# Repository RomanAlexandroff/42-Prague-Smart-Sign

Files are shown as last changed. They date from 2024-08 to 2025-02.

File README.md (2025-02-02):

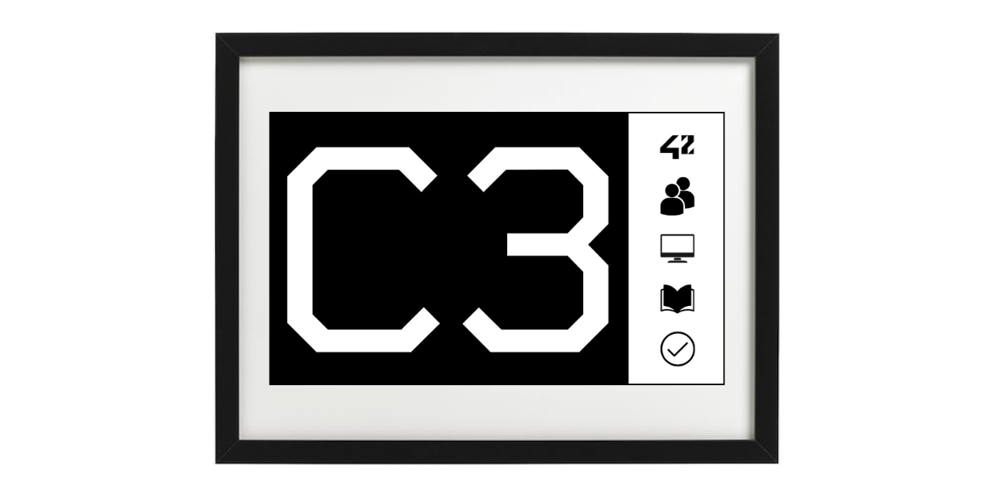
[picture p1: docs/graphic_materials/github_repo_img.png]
Repository Banner

# 42 Smart Cluster Sign
## Table of Contents

- [Introduction](#introduction)
- [Usage](#usage)
- [Features](#features)
- [Components](#components)
- [Contributing](#contributing)
- [Suggestions for Contributions](#suggestions-for-contributions)
- [Regards](#regards)
- [License](#license)
- [Conclusion](#conclusion)

## Introduction

Welcome to the README for the 42 Smart Cluster Sign — a self-sufficient information display designed to be installed on a cluster door. Its purpose is to notify students when the cluster is reserved for an exam and prevent them from accidental entering. The device automatically retrieves exam dates from Intra and displays appropriate warnings and information on its e-paper screen. In the spare time it simply displays the cluster number.

For more information, please, refer to the technical documentation in the docs folder of this repository.

## Usage

Once the 42 Smart Cluster Sign is installed and powered on, it will automatically retrieve exam dates from Intra and update the display accordingly. The device operates in the following states:
1. **Normal state**: The device displays the number of the cluster, accompanied by pictograms that depict some of the cluster use cases: cooperating with fellow peers, working on a computer, and studying from books. The last pictogram indicates "free to enter" contrasting with the "do not enter" cross pictogram that appears during exams. In case the Sign needs to communicate an issue with its operation, the pictograms are replaced with an appropriate error message, e.g.: "Low battery" or "Could not get exam info".
2. **Pre-exam warning**: On the day of an exam, the device hides the pictograms and adds a small warning note informing students of an upcoming exam later in the day. This way, students who want to settle into the room can plan their work with the cluster availability limitations in mind.
3. **1-hour countdown**: 1 hour before the exam, a countdown begins. The device no longer displays the cluster number but a full-screen sign with the minutes left until the exam, indicating to students that it is time to vacate the classroom.
4. **Exam in progress**: During the exam, the device displays a big bright-red warning sign indicating the ongoing exam. The drastically changed colour palette attracts attention, enhancing the sign's effectiveness.
5. **Post-exam state**: After the exam ends, the Sign returns to its normal state, displaying the number of the cluster.

## Features

- Highly autonomous operation: the Sign operates fully autonomously and does not require any input from the school personnel;
- Automatic exam time check: the Sign keeps track of the exams published on Intra on its own;
- Adaptation to changes: the Sign can adapt its behaviour to some unusual exam scheduling, such as last-minute cancellations, varying exam lengths, or sequences of several immediate exams;
- Exam subscribers check: if there is noone undertaking the exam, the Sigh will know it and will not block the room;
- Automatic battery charge monitoring: you will surely know when to charge the device;
- Deep Sleep mode: the microcontroller sleeps most of the time and wakes up only when it has a task to do, drastically saving the battery charge;
- Telegram enabled: control the Sign, update its security token, and receive operational information — all remotely, via your Telegram chat;
- Over The Air firmware update: develop and upload new features without the need of looking for a cable;
- Watchdog: no program failure can stop the Sign as its inner watchdog makes sure the program execution does not get stuck;
- Low-maintenance design: the 4000mAh battery ensures long periods of operation - up to a few months - between recharges, which require a standard USB-C cable and any 5V power adapter. During recharging, the Sign remains fully operational.

## Components

The following components are used in the 42 Smart Cluster Sign:
1. **Seeed Studio XIAO ESP32C3 Wi-Fi module**: provides connectivity to the Internet for retrieving exam dates, updates the display, takes care of the battery with its battery management and charging circuit — all of that while rocking modern USB-C port for charging and easy software updating.
2. **Good Display GDEY075Z08 7.5" 800x480 ePaper black/red/white SPI display**: a high-resolution display that allows for clear and easy-to-read information.
3. **Good Display DESPI-C02 universal SPI e-Paper adapter**: transforms display's FPC interface into microcontroller's SPI.
4. **4000mAh Li-ion battery with overcharge and undercharge protection**: powers the device and ensures continuous operation.
5. **IKEA RÖDALM photo frame, black, 13x18 cm**: made a good enclosure.
6. **Custom 3D-printed board**: to hold all the electronics in place.

For more information, please, refer to the bill of materials in the docs folder of this repository.

## Contributing

Contributions to the 42 Smart Cluster Sign project are welcome! If you have any ideas, bug fixes, or improvements, feel free to open an issue, fork or submit a pull request on the GitHub repository.

When contributing, please adhere to the existing code style and follow the established guidelines. Clearly describe your changes and provide any necessary documentation or tests.

## Suggestions for Contributions

**good first contributions**
- Core temperature monitoring as a safety mechanism: the temperature being too high may signal some serious hardware failure and a safety threat, e.g. the battery has the lowest maximum allowed operational temperature of 60°C — notify the Telegram chat if the temperature of the core gets at least to 50°C;
- Forced display refresh: the Sign is programed not to refresh the content on the display unless it is absolutely necessary, but this approach causes some graphical artifacts to appear with time. Add a scheduled full display cleaning. Once a week is enough. Preferably in the night when noone can see it. After the cleaning process is done, the Sign may not stay blank and shall display relevant information.
- Refactor the project to lower the number of the Common global (com_g) variables. But DO NOT alter the RTC global (rtc_g) variables unless you are absolutely certain of what you are doing;
- Add a countdown till the end of an ongoing exam like the already existing one till the start of an upcoming exam. 

**advanced contributions**
- Adding a "DO NOT ENTER!" sign that can be displayed or errased from the screen by pressing the WARNING_BUTTON button;
- Core temperature monitoring as a mechanism for detecting the battery charging process being finished: when the battery is being charged, the core temperature of the microcontroller rises approximatelly 10°C above its common operational temperature and then drops back down when finished charging — notify the Telegram chat when charging is finished. This functionality may not block the Sign from fulfilling its main goal of notifying students about exams;
- Logging error messages into a log file in the microcontroller's memory and the log file extraction mechanism;
- The direct OTA implementation - the Sign itself creates a Wi-Fi access point that you can connect to and to update the firmware without the need of a Wi-Fi modem in the middle;
- Replacing Telegram with Slack: refactoring all the Sign's Telegram functionality to work via Slack would allow integrating the Sign better into the 42 ecosystem as well as developing new functionality, e.g. notifying all the students about an upcomming exam.

The **Issues** tab of this repository may also be worth checking, as it might contain suggestions that have not yet made their way onto this list.

## Regards

This project is a group effort of various 42 students with support from the 42 Prague Bocal team. Here they are:
- **raleksan**, 42 Prague — software and electronic hardware developer. Made the idea reality,
- **gsura**, 42 Prague — idea starter and motivation supporter. Pitched the idea to Bocal so well they ended up asking for two devices,
- **cgray**, 42 Prague — hardware development. Modeled beautiful and functional inner frame for the electronics,
- **phelebra**, 42 Prague — 3D printing. Turned 3D model into high-quality pieces of hardware.
- **arosado-**, 42 Lisboa — 42 API expert. Tought how to get the data from the 42 servers,
- **jrathelo**, 42 Nice — memory wizard. Helped resolve the microcontroller's RAM overflow.

The project is based on Jean-Marc Zingg's [GxEPD2](https://github.com/ZinggJM/GxEPD2) library for e-paper displays.
The project uses the [ArduinoOTA](https://github.com/jandrassy/ArduinoOTA) library by Juraj Andrassy for the Over-The-Air software update functionality.
The Sign's Telegram Bot functionality is provided by Brian Lough's [UniversalTelegramBot](https://github.com/witnessmenow/Universal-Arduino-Telegram-Bot) library.

## License

The 42 Smart Cluster Sign project is licensed. Please, familiarise yourself with the license before using the software or working on it. The text of the license can be found in this repository.

Please note that while the project strives to provide accurate information, it is provided "as is" without any warranty. Use the project at your own risk.

## Conclusion

Thank you for your interest in the 42 Smart Cluster Sign project! We hope this README provides you with the necessary information to understand the project's purpose, features, installation process, usage, and maintenance. If you did not find the information you need, please, refer to the technical documentation in this repository. If you have any further questions or need assistance, please don't hesitate to reach out. Happy coding!

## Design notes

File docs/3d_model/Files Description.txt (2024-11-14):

The Sign Frame model

This folder contains .STL files for the Sign's
inner frame. The frame is divided into two files
to ease printing. The two printed parts must be
glued together.

The sockets fit only the parts stated in the Bill
of Materials file.

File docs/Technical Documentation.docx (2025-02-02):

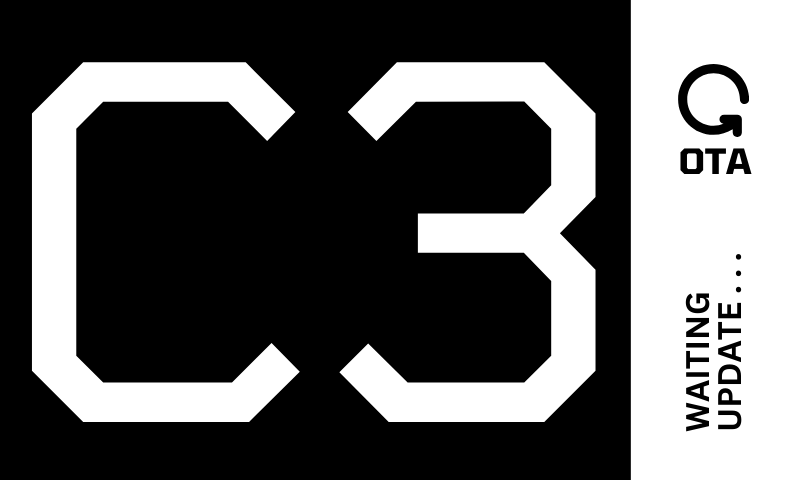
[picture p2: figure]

[This document contains detailed information about the project and was created as a go-to place to find answers to all of your HOWs and WHYs, so the software support and further project development are easier.]

[ January 2025 ]

[42 smart cluster sigN.]

[technical documentation.]

[Table of contents.]

[SUMMARY.]

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
About the project //TO-DO

Contractor's requirements

General description of the program run

Program run step-by-step //TO-DO

Getting ready to maintain and develop the project

Hardware maintenance

Program files description

The config file

Functions description

How to get exams info from Intra

Graphics //TO-DO

How to draw on the display //TO-DO

Service messages meaning //TO-DO

Libraries and their use

Bugs and suggestions how to fix them

New bugs and Future development suggestions

Suggestions for dealing with confidential information

Sources

//TO-DO:

Hardware description

Circuit diagrams and schematics

Description of the program constants

Architectural decisions explained

Power management

Safety considerations

The Don’ts of changing the program

Used terms

[ABOUT THE PROJECT.]

This project is designed to manage and display information on a smart sign for a 42 campus cluster. The sign displays various messages and images, including exam schedules, battery status, and OTA updates. It communicates with the 42 Intra API and a Telegram bot to fetch and display relevant information.

[Contractor's Requirements.]

[and how the sign matches them.]

The finished device must fulfill the following requirements:

1. Auditorium status display: the device must always display the current status of the auditorium, indicating whether it is free or if an exam is in progress.  — The Sign displays the number of the auditorium in calm black and white colours to indicate that the room is available for everyone or it displays the „exam in progress“ sign in bright red and black colours to show that the room shall not be entered by those who do not participate in the exam. The Sign is never blank.
2. Advance notification: the device should notify students in advance on exam days about the need to vacate the auditorium.  — The Sign displays a note with the exact time of the upcoming exam right from the morning of that day. 1 hour before the exam the black-white-and-red „reserve for exam“ sign with time left starts being displayed.
3. Autonomy: the device must operate independently, performing its tasks and solving problems that arise without requiring the time or intervention of the educational institution's staff.  — The Sign can connect to the Internet, access the institution server API and pull exams date and time. This is how it knows when to display the apropriate state of the auditorium. The Sign software is designed with all the common negative situations in mind which ensures the Sign does not bother anyone unless it absolutely needs to.
4. Problem reporting: the device must be capable of reporting issues that cannot be resolved without assistance from the educational institution's staff.  — When the Sign fails to resolve an unordinary situation itself and requires assistance, it displays an apropriate error message on its display as well as sends a detailed error report to its Telegram chat.
5. Support and expandability: the device should be designed for support and expansion, allowing any student of the educational institution to contribute to the project, develop new functionality, and upload new software onto the device.  — The Sign project was chosen to be made using Arduino IDE as the most beginners-friendly developing platform. The software was developed using a straightforward bare-metal approach to maintain easy-to-follow program logic. The Sign has a standart USB-C port for flashing its software, monitoring its Serial port and charging its battery. The microcontroller used in the project has inner USB controller which eliminates the need of using a UART-TTL adapter. The microcontroller pins are equipped with standart Dupont sockets which allows anyone to change used pins and add new hardware by simply connecting it to the microcontroller with Dupont cables. The Sign is securelly fixed on the wall with 4 furniture double ball catches, which at the same time allow to take the Sign off the wall for maintanance.
6. Safety: the device must ensure safety by incorporating protective elements for potentially dangerous electronic components.  — The battery used in the project has an embedded protection against shortcuts, overcharging and ungercharging, which has the ability of completely disconnecting the battery from the rest of the circuit. The battery charging IC is capable of adapting its charging power, applying lower voltages when the battery is low on charge or close to being fully charged. The charging IC generally uses slightly lower charging rate than the standart charging rate for this particular battery, which will result in the battery longer life.
7. Rechargeable operation: the device must operate on a rechargeable battery, include a common charging connector, and provide indications for the charging process and its completion.  — The Sign employs an internal high-capacity rechargeable battery, which insures a long lasting operation without the need of changing batteries. The battery can be recharged by plugging the Sign into any 5V power adapter. The Sign has a USB-C connector for recharging the battery as well as for flashing the software. The Sign employs a red LED to indicate an ongoing charging process.
8. Design compatibility: both the graphical user interface (GUI) and the physical appearance of the device must align with the established style of the educational institution's interior design.  — The body of the Sign is made of black wooden frame with mate finish, which perfectly matches the mate-black profile of the auditorium glass door. The GUI was designed inspired by the painings on the walls of the institution as well as the „42“ logo, thus nicely matching the overal style of the interiors.

[General description of the program run.]

Let's take a look at one day of the 42 Smart Cluster Sign‘s life. Let’s say that on this particular day there is an exam scheduled for 13:00 and it will last for 3 hours.

It is still night and the Sign is showing the cluster number with the default icons from the day before, while still being asleep. It is normal for the Sign to sleep all the time. It has its scheduled hours to wake up and check if something needs to be done. They are 6, 9, 12, 15, 18 and 21 o’clock (could have been changed in the program). But it is still too early.

Time passes by. Now, it is 6:00 in the morning. The Sign wakes up to check if there are exams today. It goes online, pulls the information from the Intra server and sees that there will be an exam starting at 13:00 and ending at 16:00. The Sign replaces the default icons from yesterday with a note “The cluster will be reserved for an exam today at 13:00” while still displaying the cluster number. Since there is nothing more for the Sign to do, it sets its alarm clock for 12:00 - an hour before the exam - and goes back to sleep.

It is 12 o'clock and the Sign wakes up again to get ready for the exam. It checks Intra to make sure the exam was not canceled during its sleep and that there is at least 1 person attending. If everything checks, it replaces the cluster number with a big warning sign that says: “RESERVATION! The cluster is reserved for an exam. Please, vacate it in due time. You have XX minutes left”. Instead of XX it first says 50 minutes, then 25 minutes and finally 5 minutes left.

Finally, it is 13:00. The exam begins. The Sign changes the previous warning sign for a new one, saying “DO NOT ENTER! Exam in progress!”. At this point the Sign has nothing else to do, so again it sets its alarm clock for 16:00 - the end of the exam - and goes to sleep.

At 16 o'clock the Sign wakes up, checks Intra, finds no more exams for today, replaces the warning sign with a cluster number with the default icons, sets its alarm clock until the next scheduled wake up - in this case 18:00 - and goes back to sleep.

At 18 o'clock the Sign wakes up, checks Intra and finds no more exams. Later, at 21 o’clock it wakes up for the last time today, finding nothing more to be done. Its work for today is over. It goes to sleep to wake up again the next morning at 6.

[PROGRAM RUN STEP-BY-STEP.]

STARTING THE PROGRAM

1. Turning on

2. Initializing the Serial Port

• Outputting a dash to the serial port gives time to synchronize data transfer with the computer and avoid losing important data

3. Initializing the file system

• If the file system initialization fails, the following functions will not be available: restoring the last used Telegram chat, the Secret value, and the OTA flag value after reinstalling the program, after a power outage, or after a software reset (i.e. after all cases when RTC memory data is lost); record the value of the last used Telegram chat, the Secret value and the OTA flag value

4. initialize the buttons (disabled due to bugs)

5. initialize ADC for battery measurements

6. initialize the SPI port of the display

7. check the reboot reason

• also restores the value of the last used Telegram chat, the Secret value and the OTA flag value after reinstalling the program, after a power outage or after a software reset (i.e. after all cases when RTC memory data is lost)

• also puts the device to sleep for 24 hours if the BROWN OUT detector is triggered. It is triggered if the battery charge is insufficient to continue operation. In this case, [DEVICE OPERATION ENDS HERE] until the battery is charged.

8. battery check

• due to the technical features of the device, we can determine the battery charge level only when it is almost discharged. Accurate battery measurements can be taken approximately between 3% and 0% of the battery charge. In ADC readings, this corresponds to 800 and 400.

• take 5 measurements of the charge level and calculate their average value

• all readings above 800 mean that the battery is sufficiently charged and there is no need to report a low battery - exit the function

• connect to Wi-Fi to report the battery status to Telegram

• all readings below 400 mean a completely discharged battery. Despite the fact that the BROWN OUT detector did not work in the previous step, you cannot continue working with such a low charge. We report a low battery in Telegram, display the message "Low battery" on the display and put the device to sleep for 24 hours. In this case, [DEVICE OPERATION ENDS HERE] until the battery is charged.

• indicators between 700 and 600 may mean that the device is charging

• if we still haven't exited the function, but the indicators are below 800, then the battery is already discharged, but we can still continue working. We report the discharged battery in Telegram, display the message "Low battery" on the display and continue executing the program.

9. initializing the OTA function (disabled due to blocking by the firewall)

10. switching to OTA mode (disabled due to blocking by the firewall)

11. choosing which mode to continue working in: in cluster number mode (default mode) or in exam mode

• Cluster number mode displays the cluster number + icons (on a normal day) or a warning message about the exam (on the day of the exam) or error messages (inability to receive exam data, expired Secret, low battery). This mode is active 99% of the time.

• The exam mode is activated 1 hour before the exam, shows a warning about the exam starting soon, then switches to a warning about the exam in progress and after the exam is over, switches back to the Cluster Number Mode. This mode is active only on the exam day, 1 hour before the exam + the entire exam time.

• Double checking the exam status flag in this function is necessary to switch from one mode to another. Do not change!

IN CLUSTER NUMBER MODE

1. connecting to a Wi-Fi network

2. checking incoming messages in the Telegram chat

• A new Secret may arrive via Telegram chat, which will be useful later when requesting exam data

3. synchronizing time, date and summer/winter time with the NTP server

• Without time data, reliable operation of the device cannot be ensured. If after several attempts to receive time data it was not possible, an error is displayed on the display and the device itself is put to sleep until the next scheduled awakening. In this case, [DEVICE OPERATION ENDS HERE], until we manage to get the time data during one of the future scheduled awakenings.

4. get exam data for the current day from Intra

• Without exam data, it is impossible to ensure reliable operation of the device. If after several attempts to get exam data it was not possible, an error is displayed on the display and the device itself is put to sleep until the next scheduled awakening. In this case, [DEVICE OPERATION ENDS HERE], until we manage to get exam data during one of the future scheduled awakenings.

• go to the Intra website

• log in to the Intra website

• go to the schedule page for today

• read the received HTML code until we find exam data

• clear the data from unnecessary garbage

• compare the received data with the existing data

If the data differs, we change it on the display;

If not, we leave it as it is.

Setting the time for the next activation.

Turning off the display power.

Power off.

[GETTING READY TO MAINTAIN AND DEVELOP THE PROJECT.]

## Needed hardware:

- Computer with any OS,
- USB to USB-C data cable compatible with your computer.

## Needed software:

- Arduino IDE with installed ESP-IDF plug-in,
- Telegram (smartphone app or its desktop version).

## Preparing the software tools

1. Install Arduino IDE and add the ESP-IDF extension. User-friendly instructions on how to do it may be found here:

https://randomnerdtutorials.com/getting-started-with-esp32/#esp32-arduino-ide

The online instruction suggests to download and install the latest version, but the project was built using Arduino IDE version 1.8.19 and the „esp32“ board version 3.0.7. Compatibility with the later versions was not tested, this is why it is recomended to use this, even though outdated, versions of the tools.

2. Create a folder for Arduino IDE projects. This folder will contain all the projects ever created in Arduino IDE as well as all the installed libraries. The folder may be created anywhere on your computer and may be called any name you give to it. Now, in your Arduino IDE, go to Arduino > Settings and at the top of the opened Settings window add the created folder path.
3. Make sure all the required libraries from the „LIBRARIES AND THEIR USE“ list are installed. To do so, in your Arduino IDE, go to Arduino > Add library > Manage libraries. In the opened window of the libraries manager you may find all the installed libraries as well as all the available libraries on the Internet.

It is recommended to install the libraries versions stated in the list even though they might be outdated.

4. Set the compilation target. The compiler has to be told what exact model of an ESP32 board to compile for. In case of this project it is „XIAO_ESP32C3“. To do so, in your Arduino IDE, go to Tools > Boards > ESP32 Arduino > XIAO_ESP32C3.

## Opening the project

1. Open the folder for Arduino IDE projects (the one created in step 2 above) in your terminal and use the following command to get yourself a copy of the project:

git clone https://github.com/RomanAlexandroff/42-Smart-Cluster-Sign.git

2. Open your Arduino IDE and go to File > Projects > 42-Smart-Cluster-Sign > src. Your project will open.
3. The project comes without any security-sensitive credentials. They may be found printed on the back of the Sign. Rename the „credentials-example.h“ file included in the project into „credentials.h“ and fill-in the credentials from the Sign.

DO NOT COMPROMISE THE CONFIDENTIALITY OF THE CREDENTIALS !!!

## Uploading the changes

1. Connect the Sign to your computer if you have not done so by this time.
2. Activate the software update mode. On the back of the Sign locate button B and button R. Push and hold button B. While holding button B, press button R once. Release button B. Software update mode is now active.
3. In Arduino IDE, go to Tools and set the following settings as follows:
- Upload speed: 115200
- CPU Frequency: 160 Mhz
- Flash Frequency: 80 Mhz
- Flash Mode: "QIO" the fastest mode for the flash memory
- Partition Scheme: "Minimal SPIFFS" do not use partition schemes marked with "No OTA"
- Core Debug Level: "Verbose" the most detailed debugging output into the Serial monitor
- Erase All Flash Before Sketch Upload: "Disabled"
- Port: choose the development board port.
4. In Arduino IDE, click the Upload button to start uploading.

[hardware MAINTENance.]

The Sign generally does not require any assistance, but it needs to be charged once every so often. If you have not ever charged the Sign before, it is OK, since its high-capacity inner battery allows the Sign to operate up to half a year on a single charge.

If the Sign needs to be recharged, it will indicate it by displaying the „LOW BATTERY“ note next to the cluster number as well as sending a notification into its Telegram chat.

Needed hardware:

- 5V power adapter,
- USB-C cable, compatible with the power adapter.

To charge the Sign:

1. locate a round opening on the side of the frame;
2. look inside the opening - there you should see a USB-C female connector;
3. find a cable with a USB-C male connector that fits the round opening;
4. if the cable is too short to reach the power socket, take the Sign off the wall;
5. connect the Sign to the 5V power adapter with the cable;
6. plug the 5V power adapter into a power socket;
7. look at the opening in the frame again - you should see red light comming out of it, which means that the Sign is now charging. If after a few seconds there is no red light, that may indicate a poor connection or lack of electricity.
8. wait for the red light to turn off – typically about 10 hours – that indicates that the Sign is fully charged.

[PROGRAM FILES DESCRIPTION.]

src.ino | Main file.
42-Smart-Cluster-Sign.h | Main header file that includes all necessary libraries and declares functions used across the project. Including ota.h at the bottom of the file is not coinsidential – it has to be kept below the OTA functions declarations for the OTA update to work.
battery_management.cpp | Initialize inner ADC module, measure battery voltage level, assign the results to a battery state, act upon the battery state.
bitmap_library.h | Contains all the images to be displayed on the device screen in bit-map form. The complete images list can be found in the file.
buttons_handling.cpp | Buttons initialisation and interrupt service routines.
cluster_number_mode.cpp | Everything that the Sign does outside of the exam time: gets exact time, checks exams, displays system warnings if there are any, displays cluster number.
config.h | Constants to adjust and tune the program behaviour. E.g. software version number, device name, DEBUG macro, Serial port baud rate, the Sign’s wake-up hours, Wi-Fi connection time limit, etc. More about it in the [THE CONFIG FILE.] chapter.
constants.h | Constants that are not expected to be ever changed. General constants, buttons and display SPI port configurations, display driver coniguration, images and errors enumerators.
credentials.h | Contains project confidential information, such as Intra API authorisation data, Telegram bot token, Wi-Fi access point SSID and password. If instead of credentials.h there is only credentials-example.h, then in the [GETTING READY TO MAINTAIN AND DEVELOP THE PROJECT.] chapter, please, navigate to „Opening the project“, point 3.
display_handling.cpp | Functions for outputting images and text onto the display, cluster number drawing logic, display initialization. Using display.powerOff() in the drawing functions may trigger the watchdog with high probability.
exam_mode.cpp | Everything to handle informing students about an exam and the pre-exam time.
file_system.cpp | Manages file system operations, including reading and writing to SPIFFS.
globals.h | Declares global variables and includes necessary libraries.
globals.cpp | Defines global variables used across the project.
intra_interaction.cpp | Handles interactions with the 42 Intra API, including fetching exam schedules.
ota.h | Manages OTA updates, including initializing and handling OTA update processes.
other.cpp | Contains miscellaneous functions, including sleep and delay functions.
power_down_recovery.cpp | Handles power-down recovery, including reporting reboot reasons.
telegram_bot.cpp | Manages interactions with the Telegram bot, including checking and responding to messages.
telegram_compose_message.cpp | Composes messages to be sent via the Telegram bot.
time_utilities.cpp | Contains time-related utilities, including fetching and calculating time.
watchdog.cpp | Manages the watchdog timer, including starting, stopping, and resetting the watchdog.

[The config file.]

The config.h file contains configurable parameters for tuning the software behavior of the 42 Smart Cluster Sign project. This file allows you to adjust various settings, including software version, device name, debugging options, and time-related configurations. To customize the behavior of the 42 Smart Cluster Sign project, modify the values in the config.h file according to your requirements. Ensure that the changes you make are consistent with the overall project requirements and do not conflict with other configurations.

SOFTWARE_VERSION: Defines the current version of the software. The software version number can be seen in the debugging output in the Serial monitor as well as in the Telegram chat message when the Sign receives the „/status“ command. The software version number is an essential tool for tracking bugs and the program installed on the physical device.

#define SOFTWARE_VERSION 4.32

DEVICE_NAME: Specifies the name of the device, that can be seen in the Ports list when updating via OTA.

#define DEVICE_NAME "42 Prague C3 Smart Sign"

DEBUG macro: Enables or disables serial output for debugging. Comment out the „#define DEBUG“ line to turn off serial output or uncomment it to turn it on again. The macro does not affect the Core Debug Level, which you set in the Arduino IDE Tools. Changing the DEBUG macro and/or the Core Debug Level will change the dynamic of the whole program execution which might introduce new bugs or solve existing ones.

#define DEBUG
#ifdef DEBUG
#define DEBUG_PRINTF(...) Serial.printf(__VA_ARGS__)
#define WD_RESET_INFO true
#else
#define DEBUG_PRINTF(...)
#define WD_RESET_INFO false
#endif

EXAM_SIMULATION macro: Uncomment this line to simulate an exam starting at specified time. Useful for testing exam mode execution when there are no actual exams. The macro injects fictitious information about an exam (by default, scheduled for today from 18:00 till 21:00, 4 students attending) into the message from Intra, which causes the Sign to believe that there is an actual exam that day. If needed, the fictitious exam information may be changed in the ft_exam_simulation() function, located in the other.cpp file.

#define EXAM_SIMULATION

GCC Optimization macro: Optimizes the program for faster performance. Google „GCC optimisation levels“ to find opimisation options and their meaning.

#pragma GCC optimize ("O3")

BAUD_RATE: Sets the speed of the serial communication.

#define BAUD_RATE 115200

WAKE_UP_HOURS: Defines the hours at which the Sign should wake up and check if there are any new exams. The format is a comma-separated list of hours (24-hour format), e.g. 9 means „at 9:00“ (9AM), 18 means „at 18:00“ (6PM), and so on. Note, that every hour is separated by a comma, but there is no comma after the last wake-up hour. Adhere to this format when removing or adding wake-up hours. You may change the existing wake-up hours, delete them or add new wake-up hours. There always should be at least one wake-up hour. Maximum number of wake-up hours is 24. Please, keep in mind that there is no such time as 24:00, instead use 0 (for 0:00) if you want the Sign to wake up at midnights.

#define WAKE_UP_HOURS 6, 9, 12, 15, 18, 21

RETRIES_LIMIT: Sets the maximum number of retries for getting time and exam information. Be adviced, that every other retry is 5 minutes longer than the previous one. E.g. the 1st retry will occur 5 minutes after the default try, the 2nd retry will occur 10 minutes after the 1st retry, the 3rd retry will occur 15 minutes after the 2nd retry, the 4th retry will occur 20 minutes after the 3rd retry, the 5th retry will occur 25 minutes after the 4th retry, and so forth. It is recomended not to exceed the number of 5 retries.

#define RETRIES_LIMIT 3


TIME_ZONE: Specifies the campus time zone according to the GMT standard.

#define TIME_ZONE 1

CONNECT_TIMEOUT_S: Sets the timeout for Wi-Fi connection attempts (in seconds).

#define CONNECT_TIMEOUT_S 5

DEBOUNCE_DELAY_MS: Defines the debounce delay for button presses (in milliseconds). The lower the number, the faster the button responds, but the probability of errors to occur grows.

#define DEBOUNCE_DELAY_MS 1000ul

WD_TIMEOUT_MS: Sets the timeout for the watchdog timer (in milliseconds).

#define WD_TIMEOUT_MS 8000

OTA_WAIT_LIMIT_S: Defines the maximum wait time for OTA updates (in seconds).

#define OTA_WAIT_LIMIT_S 600

[FUNCTIONS DESCRIPTION.]

# main file functions

setup(): initializes various components, including the watchdog timer, display, SPIFFS, buttons, battery, power-down recovery, battery check, Telegram bot, and OTA updates.

loop(): handles the OTA update waiting loop and calls the ft_pathfinder() function to determine the next action based on the current status.

ft_pathfinder(): function determines the next action based on the current status, including handling exam mode and cluster number mode, and then puts the device to sleep for the calculated time. The function deliberately uses two if statements since the exam_status may change its value inside the first if statement.

# Display Handling

ft_draw_text(String output, uint16_t x, uint16_t y): Draws text on the display at the specified coordinates.

ft_draw_exam_start_time(): Draws the exam start time on the display.

ft_draw_bitmap_partial_update(const unsigned char* image, uint16_t width, uint16_t height): Draws a partial bitmap image on the display.

ft_draw_colour_bitmap(const unsigned char* black_image, const unsigned char* red_image): Draws a full-color bitmap image on the display.

ft_draw_bitmap_full_update(const unsigned char* image, uint16_t width, uint16_t height): Draws a full bitmap image on the display.

ft_display_cluster_number(IMAGE_t mode): Displays the cluster number and additional images/messages based on the mode.

ft_clear_display(): Clears the display.

ft_display_init(): Initializes the display.

# Exam Mode

ft_exam_mode(): Handles the exam mode, including displaying exam-related messages and images.

# File System

ft_secret_verification(String input): Verifies the secret token.

ft_data_restore(const char* file_name): Restores data from the specified file.

ft_data_integrity_check(): Checks the integrity of the file system and restores necessary data.

ft_write_spiffs_file(const char* file_name, char* input): Writes data to the specified file in SPIFFS.

ft_read_spiffs_file(const char* file_name, char* output): Reads data from the specified file in SPIFFS.

ft_spiffs_init(): Initializes SPIFFS.

# Intra Interaction

ft_fetch_exams(): Fetches exam schedules from the 42 Intra API.

# Telegram Bot

ft_telegram_check(): Checks for new messages from the Telegram bot and handles them.

ft_compose_message(int32_t subject, int16_t days_left): Composes messages to be sent via the Telegram bot.

# Time Utilities

ft_expiration_counter(): Calculates the number of days left until the secret token expires.

ft_unix_timestamp_decoder(uint8_t* p_day, uint8_t* p_month, uint16_t* p_year): Decodes a UNIX timestamp into day, month, and year.

ft_get_time(): Fetches the current time from an NTP server.

ft_time_till_wakeup(): Calculates the time until the next wake-up.

ft_time_till_event(int8_t hours, uint8_t minutes): Calculates the time until a specified event.

ft_time_sync(unsigned int preexam_time): Synchronizes time before an exam.

# Watchdog

ft_watchdog_start(): Starts the watchdog timer.

ft_watchdog_reset(): Resets the watchdog timer.

ft_watchdog_stop(): Stops the watchdog timer.

ft_watchdog_init(): Initializes the watchdog timer.

# Other Functions

ft_go_to_sleep(uint64_t time_in_millis): Puts the device to sleep for the specified time.

ft_delay(uint64_t time_in_millis): Delays execution and puts the device into light sleep.

ft_wifi_connect(): Connects to Wi-Fi.

ft_serial_init(): Initializes the serial communication.

ft_power_down_recovery(): Handles power-down recovery, including reporting reboot reasons.

ft_exam_simulation(): Creates a fictitious exam information for the EXAM_SIMULATION macro.

[How to Get Exams Info from Intra.]

The Smart Sign does it in the following 6 steps:

1. connects to Wi-Fi,
2. connects to the 42 Intra server,
3. asks the server for a temporary access token using the UID and the Secret,
4. retreives the temporary access token from the server response,
5. asks the server for exam information for a particular campus, a particular cluster, on a particalar date,
6. retreives the exam information from the server response.

For testing purposes, this process can be recreated on a computer, in Terminal using Curl:

1. enter these variables into the Terminal

CLIENT_ID=put_your_42_API_app_UID_number_here

SECRET_ID=put_your_42_API_app_Secret_token_here

2. ask the 42 Intra server for a temporary access token

curl -X POST --data "grant_type=client_credentials&client_id=${CLIENT_ID}&client_secret=${SECRET_ID}" https://api.intra.42.fr/oauth/token

3. copy the access token from the server response and enter it as a variable into the Terminal

TKN=put_received_access_token_here

4. ask the server to send you the information about exams in the cluster C3 and put it into a .json file. 56 is the ID of the 42 Prague campus. Curl does not like square brackets [ ] in its calls, so they need to be escaped with a backslash \.

curl -H "Authorization: Bearer $TKN" "https://api.intra.42.fr/v2/campus/56/exams&filter\[location\]=C3" > c3_exams.json

If you want to filter the results down to the exact date, as the Smart Sign does, use the following call instead.

curl -H "Authorization: Bearer $TKN" "https://api.intra.42.fr/v2/campus/56/exams?filter\[location\]=C3&range\[begin_at\]=2024-07-12T05:00:00.000Z,2024-07-12T22:00:00.000Z" > c3_exams1.json

5. this command opens the .json file in the Terminal

python -m json.tool < prague_exams.json | grep "begin_at" | tr -d " ," | awk -F '"begin_at":' '{print("["++count"]:", $2)}'

[example of the 42 server access token response as the smart sign sees it.]

HTTP/2 200

date: Thu, 11 Jul 2024 13:19:37 GMT

content-type: application/json; charset=utf-8

cache-control: no-store

etag: W/"77a2df7a4e20f5f76e6364d36bc76e8a"

pragma: no-cache

set-cookie: _mkra_stck=15e20a8020c702e70007eb1e185a06fb%3A1720703982.2018037; path=/; max-age=10; expires=Thu, 11 Jul 2024 13:19:47 -0000; HttpOnly

status: 200 OK

vary: Origin,Accept-Encoding

x-rack-cors: preflight-hit; no-origin

x-request-id: 3d153728-82b5-48a0-84e7-7c1f1efe598a

x-runtime: 0.076367

cf-cache-status: DYNAMIC

report-to: {"endpoints":[{"url":"https:\/\/a.nel.cloudflare.com\/report\/v4?s=5%2Bb21KLqrzLETXPtKW2gerMAMrEPjiLAWT6eRUKeyuOVy3b5pvEr6Tc7D%2BMB%2BB4gqUHrTyXWaYy01CmZjQqUGReP7COyDKfBhKpl75Kwd%2FWrMWCVZD%2FkWhvM1iHF0V43hw%3D%3D"}],"group":"cf-nel","max_age":604800}

nel: {"success_fraction":0,"report_to":"cf-nel","max_age":604800}

server: cloudflare

cf-ray: 8a191610cec6bc03-FRA

{"access_token":"03e4cb9b861dad6c49f2267cf97bd18a942507efa7840dc971008d264596cf89","token_type":"bearer","expires_in":6564,"scope":"public","created_at":1720703340,"secret_valid_until":1722585613}

[example of the 42 server EXAM INFORMATION response as the smart sign sees it.]

HTTP/1.1 200 OK

Date: Thu, 28 Nov 2024 06:10:13 GMT

Content-Type: application/json; charset=utf-8

Transfer-Encoding: chunked

Connection: close

Cache-Control: max-age=0, private, must-revalidate

etag: W/"4dc462b36f78c9e055076113bae0d605"

status: 200 OK

vary: Origin,Accept-Encoding

x-application-id: 67990

x-application-name: 42PRAGUEAPI SCREEN

x-application-roles: None

x-content-type-options: nosniff

x-fast: false

x-frame-options: SAMEORIGIN

x-hourly-ratelimit-limit: 1200

x-hourly-ratelimit-remaining: 1199

x-page: 1

x-per-page: 30

x-rack-cors: preflight-hit; no-origin

x-request-id: 1d409b60-b763-4e10-af5a-8fe35593b80d

x-runtime: 0.196901

x-secondly-ratelimit-limit: 2

x-secondly-ratelimit-remaining: 1

x-total: 1

x-xss-protection: 1; mode=block

cf-cache-status: DYNAMIC

Server: cloudflare

CF-RAY: 8e9831883e36b353-PRG

9fa

[{"id":21213,"ip_range":"10.11.0.0/16,10.12.0.0/16,10.13.0.0/16","begin_at":"2024-11-28T14:00:00.000Z","end_at":"2024-11-28T17:00:00.000Z","location":"C3","max_people":25,"nbr_subscribers":4,"name":"EXAM STUD","created_at":"2024-11-22T08:20:02.386Z","updated_at":"2024-11-27T23:40:57.806Z","campus":{"id":56,"name":"Prague","time_zone":"Europe/Prague","language":{"id":2,"name":"English","identifier":"en","created_at":"2015-04-14T16:07:38.122Z","updated_at":"2024-11-18T11:22:47.733Z"},"users_count":1335,"vogsphere_id":52,"country":"Czech Republic","address":"AFI CITY TOWER Kolbenova 1021/9 Praha 9 - Vysočany","zip":"19000","city":"Prague","website":"https://42prague.com","facebook":"https://www.facebook.com/42Prague","twitter":"","active":true,"public":true,"email_extension":"42prague.com","default_hidden_phone":false},"cursus":[{"id":21,"created_at":"2019-07-29T08:45:17.896Z","name":"42cursus","slug":"42cursus","kind":"main"},{"id":21,"created_at":"2019-07-29T08:45:17.896Z","name":"42cursus","slug":"42cursus","kind":"main"},{"id":21,"created_at":"2019-07-29T08:45:17.896Z","name":"42cursus","slug":"42cursus","kind":"main"},{"id":21,"created_at":"2019-07-29T08:45:17.896Z","name":"42cursus","slug":"42cursus","kind":"main"},{"id":21,"created_at":"2019-07-29T08:45:17.896Z","name":"42cursus","slug":"42cursus","kind":"main"}],"projects":[{"id":1320,"name":"Exam Rank 02","slug":"exam-rank-02","difficulty":0,"parent":null,"children":[],"attachments":[],"created_at":"2019-07-29T09:05:05.890Z","updated_at":"2024-11-25T08:53:45.680Z","exam":true,"git_id":null,"repository":null},{"id":1321,"name":"Exam Rank 03","slug":"exam-rank-03","difficulty":0,"parent":null,"children":[],"attachments":[],"created_at":"2019-07-29T09:05:15.263Z","updated_at":"2024-11-25T08:56:10.466Z","exam":true,"git_id":null,"repository":null},{"id":1322,"name":"Exam Rank 04","slug":"exam-rank-04","difficulty":0,"parent":null,"children":[],"attachments":[],"created_at":"2019-07-29T09:05:24.256Z","updated_at":"2024-11-25T08:56:32.456Z","exam":true,"git_id":null,"repository":null},{"id":1323,"name":"Exam Rank 05","slug":"exam-rank-05","difficulty":0,"parent":null,"children":[],"attachments":[],"created_at":"2019-07-29T09:05:32.360Z","updated_at":"2024-11-25T08:56:53.071Z","exam":true,"git_id":null,"repository":null},{"id":1324,"name":"Exam Rank 06","slug":"exam-rank-06","difficulty":0,"parent":null,"children":[],"attachments":[],"created_at":"2019-07-29T09:05:39.838Z","updated_at":"2024-11-25T08:57:29.269Z","exam":true,"git_id":null,"repository":null}]}]

0

[graphics.]

[HOW TO DRAW ON THE DISPLAY.]

COORDINATES, SIZES IN PIXELS AND ROTATION

In the setRotation(uint8) function you may set how the window you want to output on the display will be turned compared to the display physical orientation. All the displays have their default physical orientation, but it may vary from display to display, so finding out the display's default physical orientation is the starting point for any work with display graphics. It is easy to do: take a look at the display's physical appearence, note the side where a ribbon of wires sticks out of it — that's the bottom side of this display's default physical orientation. Knowing that, we now can set the rotation:

setRotation(0) — for the default rotation, it is equal to the display default physical orientation

setRotation(1) — will rotate the window 90 degrees clockwise comparing to the display default physical orientation

setRotation(2) — will rotate the window 180 degrees (or simply flips it up-side-down) comparing to the display default physical orientation

setRotation(3) — will rotate the window 270 degrees clockwise comparing to the display default physical orientation

Keep in mind that however you rotate the window, its system of coordinates always rotates with it. So, the 0,0 coordinates are always in the TOP LEFT corner of your window.

When dealing with the Partial Update windows, it is important to remember about one unobvious limitation of the e-paper controller: partial update window size and position are on byte boundary with physical x direction. Meaning that the controller may set the horisontal window boundaries only on every 8th pixel comparing to its default physical orientation. Let's summ it up with a simple rule that is easy to follow:

The value of x and the value of width should be multiple of 8, for rotation 0 or 2,

the value of y and the value of hight should be multiple of 8, for rotation 1 or 3.

The function setPartialWindow(x, y, width, height) allows us to create a window of any size and, instead of the whole display, update only the content of this window. It is very useful feature since it is much faster than the conventional full display update with the setFullWindow() function. Moreover, this type of an update does not flicker. So, if you need to get rid off of the flickers between the slides, with setPartialWindow(x, y, width, height) you may set the whole display as a Partial Update window. But be careful as THE FIRST UPDATE AFTER TURNING ON OR RESET SHALL ALWAYS BE THE FULL DISPLAY UPDATE with the setFullWindow() function. Otherwise the display may be irrevertably stuck on the last image for ever.

It may be useful to note the relationship between the setPartialWindow(x, y, width, height) and the setRotation(uint8) functions. Some may think that setRotation(uint8) may turn a Partial Update window created with the setPartialWindow(x, y, width, height) function. And it is true, but only to some extent. setRotation(uint8) does not turn Partial Update windows, but it actually turns the whole display window orientation with Partial Update windows inside of it. That is why when we change the display orientation with the setRotation(uint8) function, we also need to remember that the system of coordinates for x and y in the setPartialWindow(x, y, width, height) also changes. And when the system of coordinates changes, the understanding of width and height changes with it. E.g. if while setRotation(0) the window's width is 800 and the window's height is 480, then while setRotation(1) the window's width becomes 480 and the window's height becomes 800.

For some unexplainable reason when it comes to the text body coordinates, their logic is very different from windows and images. The x and y coordinates point to the bottom left corner of the first line of text even if there are multiple lines of text. In comparison, the common logic for the windows and bitmaps coordinates are that their x and y point to the top left corner of the image. So, if you used display.setCursor(x, y) command to output the word HELLO onto the display, the x and the y there would point to the very bottom left pixel of the letter H.

The coordinates logic is also tricky when it comes to the command

display.getTextBounds(output, 0, 0, &text_box_x, &text_box_y, &text_width, &text_height)

This command can view any text as the smallest box that can accomodate the given text and give you all the needed information to create such a box on the screen. It is very useful when you want to update a piece of text or a single character on your display instead of the whole display. The function takes a few parameters: the text in the form of a String varible (here it is "output"), x and y coordinates of the area you want to place the text (here they are "0, 0" - the top left corner of the display), pointers to x and y coordinates (this is how you will get x and y coordinates for the top left corner of the box for the text), pointers to the width and height (this is how you will get width and height values of the box for the text). It is not required to change the "0, 0" coordinates because this function does not place anything anywhere - it uses this values only for calculations. Though, it is important to remember, that when you use the default "0, 0" coordinates, the value in the text_box_y variable will be NEGATIVE. Why does this happen? Exactly because of the difference in the coordinates logic between texts and windows/bitmaps/boxes. If you remember, x and y for texts point to the BOTTOM left pixel of the text; but x and y for windows/bitmaps/boxes point to their TOP left pixel. The display.getTextBounds tries to compensate this logic difference. E.g. if you were to place the word HELLO with the 10 size font into the top left corner (0, 0) of the display, you would need to call setCursor(0, 10); but if you were to creare a partial update window in the the top left corner (0, 0) of the display to update that text, you would need to call setPartialWindow(0, 0, text_width, 10).

But noone has time to deal with different coordinates logic! We want to give the function the text and just one set of x,y coordinates and the text shall simply aline with my partial update window automatically! That's where the getTextBounds may help. In our example our target display coordinates are x = 0, y = 0 (the top left corner), so let's place HELLO in there with a partial display update:

display.setTextSize(10);

display.getTextBounds("HELLO", 0, 0, &text_box_x, &text_box_y, &text_width, &text_height);

// now text_box_x has value 0, text_box_y == -10, text_width == HELLO-width value (I don't know it), text_height == 10

display.setPartialWindow(x, y, text_width, text_height);

// that creates a window in the top left corner of the display, HELLO-width pixels wide and 10 pixels high

display.setCursor(x - text_box_x, y - text_box_y);

// this is how we compensate for the text coordinates logic: for x (0 - 0 = 0) and for y (0 - (-10) = 10) coordinates

display.print("HELLO");

[SERVICE MESSAGES MEANING.]

[LIBRARIES AND THEIR USE.]

The project was built in Arduino IDE 1.8.19.

It uses board 'esp32' version 3.0.7

The libraries in bold are explicitly included in the project.

Arduino.h | | String variables manipulations
LittleFS | 2.0.0 | stores data even without electricity (Telegram chat number, Secret, OTA flag value)
FS | 2.0.0 | dependency for the LittleFS library
ArduinoOTA | 2.0.0 | for the Over The Air update functionality
WiFiUdp | 2.0.0 | dependency for the ArduinoOTA library
ESPmDNS | 2.0.0 | dependency for the ArduinoOTA library
Update | 2.0.0 | dependency for the ArduinoOTA library
time.h | | gets NTP Server date and time; deciphers UNIX timestamp for the SECRET expiration date
stdio.h | | provides printf() function for the DEBUG macro
stdint.h | | provides fixed-width integer types
esp_system.h | | allows to use ESP-IDF native functions
esp_sleep.h | | allows to use the Deep Sleep power-saving functionality
driver/adc.h | | for battery charge measurements
esp_task_wdt.h | | program execution watchdog
Wire | 2.0.0 | for SPI reconfiguration in the ft_display_init function
SPI | 2.0.0 | dependency for the Wire library
GxEPD2_3C | 1.5.2 | 3-coloured version of the GxEPD2 library for e-paper displays
GxEPD2_BW | 1.5.2 | dependency for the GxEPD2_3C library
Adafruit_GFX_Library | 1.11.8 | dependency for the GxEPD2_3C library
Adafruit_BusIO | 1.14.4 | dependency for the GxEPD2_3C library
Fonts/FreeSansBold24pt7b.h | | the fonts come from the Adafruit GFX library which gets called by the GxEPD2 library
WiFi | 2.0.0 | for Wi-Fi functionality
WiFiClientSecure | 2.0.0 | for secure HTTPS requests
UniversalTelegramBot | 1.3.0 | Telegram bot; for wireless SECRET update and low battery notifications
ArduinoJson | 6.21.3 | dependency for the UniversalTelegramBot library

[BUGS AND SUGGESTIONS HOW TO FIX THEM.]

Display does not work / does not draw an image.

- you may have miscalculated the image coordinates and the image gets drawn outside of the display field of coordinates. Remember that setRotation also rotates the display field of coordinates. Remember that coordinates always point to the top left corner of an image, but for a text it is the bottom left pixel of the first character in the first line.
- you may have misaligned the image with the partial update window if you are using one. Remember that even when you draw an image in a partial update window, you use the whole display field of coordinates to place it; a partial update window does not have its own field of coordinates.
- the display driver memory may be full. Run your program and open the Serial monitor. When an image gets drawn on the display, in the Serial monitor it says “Updating xxxxxxxxxx” where xxxxxxxxxxxx is a very long number that can be different each program run. Among all the outputted messages find the “Updating” message that corresponds to your image being drawn. Now look higher and find the “Power on” message. Keep looking higher and find the “Power off” message, it should not be separated from your “Updating” message by other “Updating” messages. If you cannot find it, it means that this is a bug. To fix it, in your code use the function to force the display to power off before drawing the image. The display will power back on automatically.

Flash memory became too small to accomodate the software.

- ESP32C3 comes with 4MB of onboard memory. This project‘s default memory partition scheme "Minimal SPIFFS (1.9MB APP with OTA/190KB SPIFFS)" provides exactly 1 966 080 Bytes for the software program, another 1 966 080 Bytes as an OTA buffer and 194 560 Bytes for the file system files storage space.
- Commenting out the #pragma GCC optimize ("O3") line in config.h will make the compiler optimize the code for lower software image size instead of faster program performance. That may win over about 2-3 KB of memory space.
- Before compiling the software image, in the „Tools“ menu of Arduino IDE, go to the Core Debug Level and switch it from „Verbose“ to „None“ — this simple step can free up to 3% of the memory space.
- Downgrade the project from the esp32 board version 3.0.7 to the esp32 board version 2.0.16. This step may require to refactor the watchdog and the battery management functionalities, but it may free up to 10% of the memory space.
- In the „Tools“ menu of Arduino IDE, go to the Partition Scheme and choose the option „Huge APP (3MB No OTA/1MB SPIFFS)“. Doing so will free up a whopping 30% of the memory space. Unfortunatelly, the Over-The-Air update functionality will not have a buffer for its work and so will no longer be available. At this point the OTA functionality code may well be removed from the project.

Some RTC variables loose thier values over the Deep Sleep.

- There could be more than one reason to it, but most likely it is caused by the RTC memory overflow. Try removing some less important variables from the RTC domain. The String Object type variables (or simply String variables) are known to have a big overhead and thus to take a lot of memory space. It is encouraged not to use them in the RTC domain at all.

DEBUG_PRINTF does not output a message.

- the DEBUG_PRINTF macro cannot output String type variables natively. To do that, you need to explicitly cast the String variable into the C-style string with c_str() command. Look for examples in the program code.

Serial monitor is empty / outputs gibberish.

- check the DEBUG macro in the config.h file. The DEBUG definition should not be commented out for the Serial output to work. Additionally, you can set the Core Debug Level to "Verbose" in the Arduino IDE Tools to get detailed information about the firmware processes.
- make sure that the baud rate in the Serial monitor is set to the same baud rate as in the config.h file.
- you may encounter such behaviour right after the software update. It is normal. Try closing and opening again the Serial monitor window. If that does not help, push the Reset ("R") button on the module.

Serial monitor skips some messages / does not show some messages.

- it is a common situation at the beginning of the program. Serial communication between the computer and the microcontroller needs time to stabilise and synchronise itself. ESP32-C3 USB Serial is especially prone to this issue. To overcome it, increase the delay inside of ft_serial_init() or add a few empty messages to be outputted after the Serial.begin() command. You may well try to implement both of the suggested solutions at the same time.

Wi-Fi does not connect / reconnect without apparent reason.

- thoroughly check your network SSID and password spelling. Surprisingly, it is a very widely spread cause. A single character written small instead of capital may easily prevent you from connecting.
- make sure not to use ft_delay() in any of your functions responsible for connecting or reconnecting to Wi-Fi. The ft_delay() function not only delays the program execution but also puts the microcontroller's inner Wi-Fi module to sleep. Using ft_delay() in functions responsible for retrieving information from the Internet may result in unexpected behaviour. If you are not sure that using ft_delay() is safe in your particular function, use delay() instead.

OTA does not work. Cannot see the device in the ports list.

- make sure that the Sign and your computer are connected to the same Wi-Fi network and to the same Wi-Fi modem within that network. In the Telegram chat prompt the Sign with the „/status“ command to see the MAC address of the Wi-Fi modem it is currently connected to.
- try closing and reopening Arduino IDE.
- the school firewall may be blocking OTA connection. Ask your campus system administrator if it could be overcome.

Adding multiple Strings together with the “+” command causes compilation error.

- strangely, sometimes the compiler may not like it in one part of the code and be completely fine with it in another. The solution is to explicitly cast the variable after the first “+” command into String with the String(your_variable_or_text) command. Understandably, it is strange to cast a String variable into String, but it works.

WARNING: Skipping SSL Verification. INSECURE!

- not a bug.
- this message appears when connecting to the Intra server and is caused by the following line in the intra_interaction.cpp file: „client1.setInsecure();“.
- one one hand, it can be solved by getting and setting up a certificate for this connection. On the other hand, it does not affect the program run at all and can be ignored.

setSocketOption(): fail on 0, errno: 9, "Bad file number"

- a minor issue and does not necessarily indicate a problem with the program.
- this message may appear when the Smart Sign fails the first attempt to get a server response from the Intra server and goes for the second or third attempt.
- this error can occur when you try to set a socket option on a socket that has already been closed or is in the process of being closed. This can happen during the transition between closing the previous connection and opening a new one. As long as the SSL/TLS communication with the Intra server is functioning correctly after the reconnection, this error can generally be ignored.

spiAttachMISO(): SPI Does not have default pins on ESP32C3!

- not a bug.
- This message appears when the microcontroller assigns pins for the display SPI port. In this project we do not use the MISO pin (thus the „-1“ value defined for the SPI_MISO_PIN in the constants.h file).

401 Unauthorized. Error! Server response came without the Access Token.

- often happens when something is wrong with the Secret token authentication, commonly with the Secret token itself. Most likely, an extra character was added to your Secret token somewhere along the way. The character may even not to be visible in the Serial monitor. It may happen when you write to or read from the filesystem files. Try using trim() on the variable (e.g. your_string_variable.trim();), it will remove spaces and/or new line signs at the beginning and at the end of the string.
- rarely may happen due to the Intra server maintenance. There is no solution to it but to wait.

Compilation error: “Section .dram0.bs 'Will Not Fit In Region Dram0_0_seg' Region.`Dram0_0_seg 'Overflowed by 9648 Bytes. Collect2: Error: LD Returned 1 Exit Status”

- it means that the program takes more RAM space than it is available. DRAM stands for Data Random Access Memory and is used for data.
- This error may be caused for example by excessive use of global variables, large arrays, big buffers, etc.
- The most likely reason for this error in this project is the display buffer being too big. The ESP32 and the ESP32-S2 are especially prone to this issue. To overcome this problem the display buffer size should be reduced. It can be done in the display instantiation. Here is the default display buffer instantiation: GxEPD2_3C<GxEPD2_750c_Z08, GxEPD2_750c_Z08::HEIGHT> display(GxEPD2_750c_Z08(SPI_SS_PIN, DC_PIN, RST_PIN, BUSY_PIN)); And here is a reduced display buffer instantiation: GxEPD2_3C<GxEPD2_750c_Z08, GxEPD2_750c_Z08::HEIGHT/2> display(GxEPD2_750c_Z08(SPI_SS_PIN, DC_PIN, RST_PIN, BUSY_PIN));
- Less likely reason for this error is an excessive use of the global scope for data. To solve it reduce the number of global variables, use the file system to store the data instead of arrays.

Software update fails while trying to connect to the microcontroller board

- Go into the "Tools" menu and change the Upload Speed to 115200. Sometimes the IDE automatically sets the Upload Speed to the highest value and your board may happen not to support it.

[INTRA] Error! Server response to the Access Token request was not received.

[INTRA] Error! Server response to the Exam Time request was not received.

- If any of these error messages keep appearing in the Serial monitor, it is likely that it is not enough time for the Intra server to proceed the request from the Sign. Try going into the config.h file and incrementally increasing the value of the SERVER_WAIT_MS macro by 500 milliseconds each time.

[NEW bugs and Future development suggestions.]

All newly discovered bugs should be documented in the "Issues" tab of the project's GitHub repository. This helps keep track of problems and facilitates community engagement in resolving them.

Any suggestions for future development or enhancements can be added to the "Suggestions for Contributions" section in the README file of the project's GitHub repository. This allows everyone to see potential improvements and participate in developing them.

[Suggestions for dealing with confidential information.]

[External Information Sources.]

NTP (time) server API documentation

https://cplusplus.com/reference/ctime/tm/

GDEY075Z08 display data sheet

https://www.laskakit.cz/user/related_files/gdey075z08.pdf

GDEY075Z08 display code example

https://github.com/LaskaKit/Testcode_examples/blob/main/Displays/E-Paper/7-50/GDEY075Z08_GxEPD2/GDEY075Z08_GxEPD2.ino

UC8179 - the display hardware driver - data sheet https://www.laskakit.cz/user/related_files/uc8179.pdf

GxEPD2 library - the display software driver - online page

https://github.com/ZinggJM/GxEPD2

Online forum for GxEPD2 library proubleshooting discussions

https://forum.arduino.cc/t/good-display-epaper-for-arduino/419657

ESP32 RAM issue discussion page

https://github.com/espressif/arduino-esp32/issues/1163

XIAO ESP32C3 development board instruction page

https://wiki.seeedstudio.com/XIAO_ESP32C3_Getting_Started/

Video tutorial about troubleshooting the ArduinoOTA library

https://www.youtube.com/watch?v=z_btZfxrS48

The best instruction ever on the buttons implementation with ESP32

https://esp32io.com/tutorials/esp32-button

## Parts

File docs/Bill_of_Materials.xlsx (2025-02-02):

Bill of Materials. 42 Smart Cluster Sign — 7.5'' BLACK/RED/WHITE DISPLAY, BATTERY-POWERED.
№ | STATUS | ITEM | QUANTITY | PURCHASE PRICE | SUPPLIER | DELIVERY ESTIMATION | PRODUCT PAGE ON THE INTERNET
1 | acquired | 7.5'' 800x480 E-Paper Display, Black-Red-White | 1 | 1458 CZK | LaskaKit.cz | 4 days | https://www.laskakit.cz/good-display-gdey075z08-7-5--800x480-epaper-cerveny-displej/
2 | acquired | DESPI-C02 universal SPI display adapter | 1 | 188 CZK | LaskaKit.cz | 4 days | https://www.laskakit.cz/good-display-despi-c02-univerzalni-spi-e-paper-adapter/
3 | acquired | Seeed Xiao ESP32-C3 - WiFi/Bluetooth MCU module | 1 | 169 CZK | Botland.cz | 5 days | https://botland.cz/moduly-wifi-a-bt-esp32/21859-seeed-xiao-esp32-c3-wifi-bluetooth-seeedstudio-113991054.html
4 | acquired | External WiFi antenna 2.4G, 45x10mm, IPEX1 | 1 | 28 CZK | LaskaKit.cz | 4 days | https://www.laskakit.cz/wifi-45x10mm-antena-2-4g--5db-u-fl--ipex1--konektor/
5 | acquired | Internal wiring | 3 meters | 39 CZK | GME.cz | self pick up | https://www.gme.cz/v/1511716/kls-awg28-09h-plochy-vicezilovy-kabel
6 | acquired | Battery, LiPol, 4000mAh, 3.7V | 1 | 318 CZK | LaskaKit.cz | 4 days | https://www.laskakit.cz/geb-lipol-baterie-785084-4000mah-3-7v-jst-ph-2-0/
7 | acquired | IKEA RÖDALM 13x18 photo frame, black | 1 | 69 CZK | IKEA | self pick up | https://www.ikea.com/cz/cs/p/roedalm-ram-cerna-10548867/
8 | acquired | Keyboard push-buttons 15x15 mm | 3 | 99 CZK | Botland.cz | 5 days | https://botland.cz/tlacitkove-a-elektricke-spinace/22205-mechanicke-klicove-spinace-kailh-clicky-male-mechanicke-tlacitko-modre-1ks-adafruit-5123.html
9 | acquired | Ball latch 43 mm, brass | 4 | 300 CZK | Hornbach | self pick up | https://www.hornbach.cz/p/kulickova-zapadka-43-mm-mosaz/6384677/
10 | acquired | Double-sided see-through sticking tape | 1 | 259 CZK | Hornbach | self pick up | https://www.hornbach.cz/p/roxolid-oboustranna-paska-5-m-transparentni-19-mm/5722602/
11 |  | Delivery LaskaKit.cz | 1 | 90 CZK | Zasilkovna | —
12 |  | Delivery Botland.cz | 1 | 100 CZK | PPL | —
 |  | TOTAL |  | 3117 CZK
 |  |  |  | ≈ 124 EUR

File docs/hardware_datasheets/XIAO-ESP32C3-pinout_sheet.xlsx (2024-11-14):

Name | No. | Type | Power Domain | Function |  |  | Seeed Studio XIAO ESP32C3 pin definitions and functions |  |  |  | BOOT
LNA_IN | 1 | I/O | — | RF input and output |  |  |  |  |  |  | JTAG/SWD
VDD3P3 | 2 | PA | — | Analog power supply |  |  |  |  |  |  | UART
VDD3P3 | 3 | PA | — | Analog power supply |  |  |  |  |  |  | SPI
XTAL_32K_P | 4 | I/O/T | VDD3P3_RTC | GPIO0 | ADC1_CH0, | XTAL_32K_P |  |  |  |  | ALL PWM
XTAL_32K_N | 5 | I/O/T | VDD3P3_RTC | GPIO1 | ADC1_CH1, | XTAL_32K_N |  |  |  |  | USB
GPIO2 | 6 | I/O/T | VDD3P3_RTC | GPIO2 | ADC1_CH2, | FSPIQ | A0 | D0 |  |  | Analog
CHIP_EN | 7 | I | VDD3P3_RTC | High: on, enables the chip. Low: off, the chip powers off. Note: Do not leave the CHIP_EN pin floating. |  |  |  |  |  |  | IIC
GPIO3 | 8 | I/O/T | VDD3P3_RTC | GPIO3 | ADC1_CH3 |  | A1 | D1 |  |  | Digital
MTMS | 9 | I/O/T | VDD3P3_RTC | GPIO4 | ADC1_CH4, FSPIHD, MTMS |  | A2 | D2 |  |  | GPIO
MTDI | 10 | I/O/T | VDD3P3_RTC | GPIO5 | ADC2_CH0, FSPIWP, MTDI |  | A3 | D3 |  |  | QTouch
VDD3P3_RTC | 11 | PD | — | Input power supply for RTC |  |  |  |  |  |  | LED
MTCK | 12 | I/O/T | VDD3P3_CPU | GPIO6 | FSPICLK, MTCK |  |  | D4 | SDA
MTDO | 13 | I/O/T | VDD3P3_CPU | GPIO7 | FSPID, MTDO |  |  | D5 | SCL
GPIO8 | 14 | I/O/T | VDD3P3_CPU | GPIO8 |  |  |  | D8 |  | SCK
GPIO9 | 15 | I/O/T | VDD3P3_CPU | GPIO9 |  |  |  | D9 |  | MISO
GPIO10 | 16 | I/O/T | VDD3P3_CPU | GPIO10 | FSPICS0 |  |  | D10 |  | MOSI
VDD3P3_CPU | 17 | PD | — | Input power supply for CPU IO
VDD_SPI | 18 | I/O/T/PD | VDD3P3_CPU | GPIO11 | output power supply for flash6
SPIHD | 19 | I/O/T | VDD3P3_CPU | GPIO12 | SPIHD
SPIWP | 20 | I/O/T | VDD3P3_CPU | GPIO13 | SPIWP
SPICS0 | 21 | I/O/T | VDD3P3_CPU | GPIO14 | SPICS0
SPICLK | 22 | I/O/T | VDD3P3_CPU | GPIO15 | SPICLK
SPID | 23 | I/O/T | VDD3P3_CPU | GPIO16 | SPID
SPIQ | 24 | I/O/T | VDD3P3_CPU | GPIO17 | SPIQ
GPIO18 | 25 | I/O/T | VDD3P3_CPU | GPIO18 | USB_D-
GPIO19 | 26 | I/O/T | VDD3P3_CPU | GPIO19 | USB_D+
U0RXD | 27 | I/O/T | VDD3P3_CPU | GPIO20 | U0RXD |  |  | D7 | RX | SS
U0TXD | 28 | I/O/T | VDD3P3_CPU | GPIO21 | U0TXD |  |  | D6 | TX
XTAL_N | 29 | — | — | External crystal output
XTAL_P | 30 | — | — | External crystal input
VDDA | 31 | PA | — | Analog power supply
VDDA | 32 | PA | — | Analog power supply
GND | 33 | G | — | Ground

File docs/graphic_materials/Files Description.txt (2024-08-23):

NAME				SIZE		USAGE					NOTES

github_repo_img.png		1280 × 640	GitHub repository description
telegram_bot_logo.png		512 × 512	Telegram Bot logo in Telegram app
cluster_number_img.bmp		630 × 480	Default UI outside of exams		Does not cover the whole screen - to be used with 170×480 images.
default_cluster_icons.bmp	170 × 480	Default UI outside of exams		Means that there are no exams and no issues. 
reserve_note_img.bmp		170 × 480	UI. On exam days			Shows the exact time of the closest exam that day.
secret_expire_img.bmp		170 × 480	UI. Error message			Notifies that the Secret token is expired and the Sign cannot proceed its work.
intra_error_img.bmp		170 × 480	UI. Error message			The Sign cannot retrieve the exam info because of an issue not caused by the Secret.
low_battery_img.bmp		170 × 480	UI. Error message			Notifies that the Sign has to be charged as soon as possible	
preexam_50mins_img.bmp		800 × 480	UI. On exam days, 1 hour before exam	Warns students to leave the cluster. 50 minutes left until the exam				
preexam_25mins_img.bmp		800 × 480	UI. On exam days, 1 hour before exam	Warns students to leave the cluster. 25 minutes left until the exam
preexam_5mins_img.bmp		800 × 480	UI. On exam days, 1 hour before exam	Warns students to leave the cluster. 5 minutes left until the exam
exam_warning_img.bmp		800 × 480	UI. On exam days, during the exam	Warns students not to enter

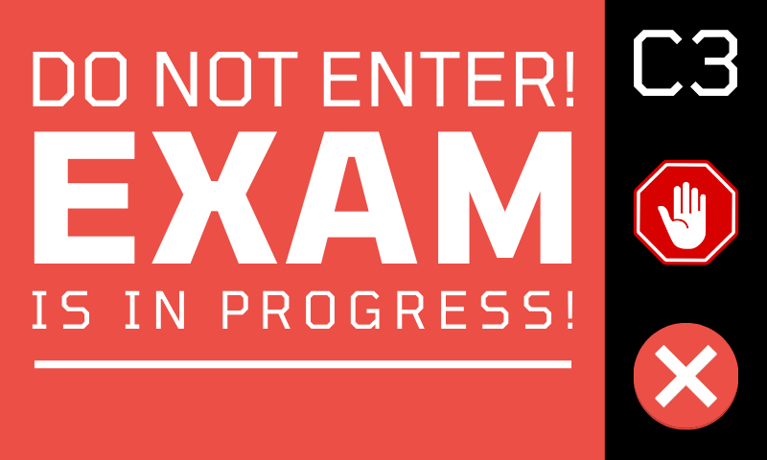
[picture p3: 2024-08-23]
docs/graphic_materials/exam_warning_img.bmp

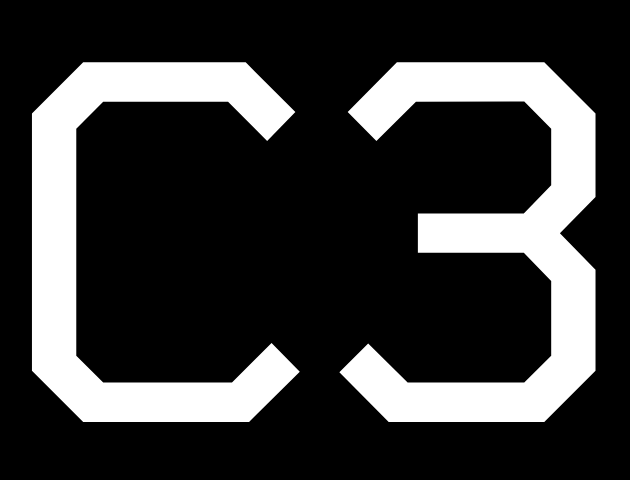
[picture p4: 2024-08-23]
docs/graphic_materials/cluster_number_img.bmp

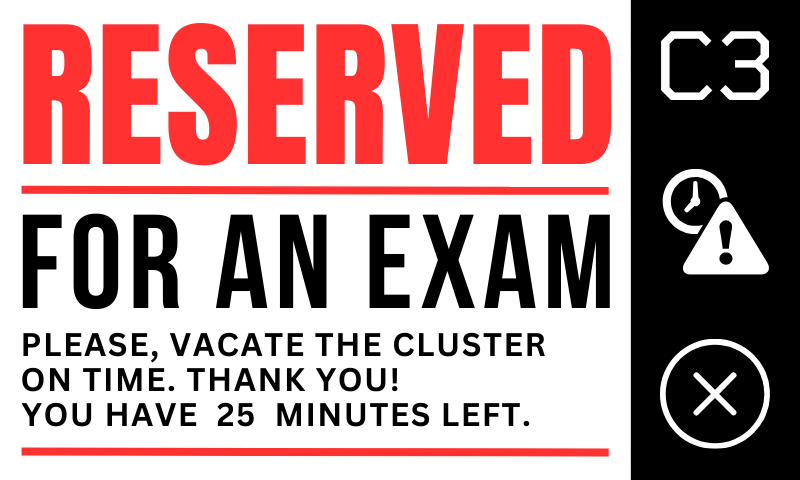
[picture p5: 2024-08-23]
docs/graphic_materials/preexam_25mins_img.bmp

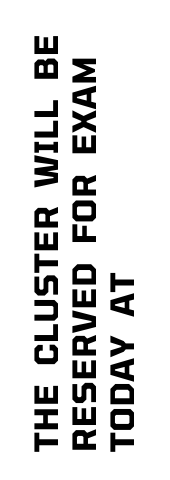
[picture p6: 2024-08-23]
docs/graphic_materials/reserve_note_img.bmp

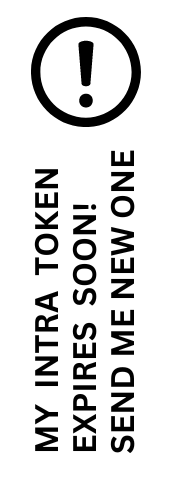
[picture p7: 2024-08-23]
docs/graphic_materials/secret_expire_img.bmp

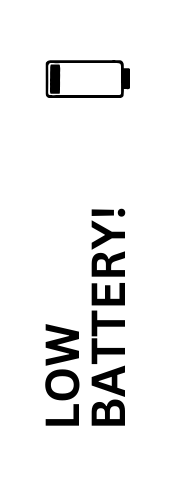
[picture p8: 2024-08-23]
docs/graphic_materials/low_battery_img.bmp

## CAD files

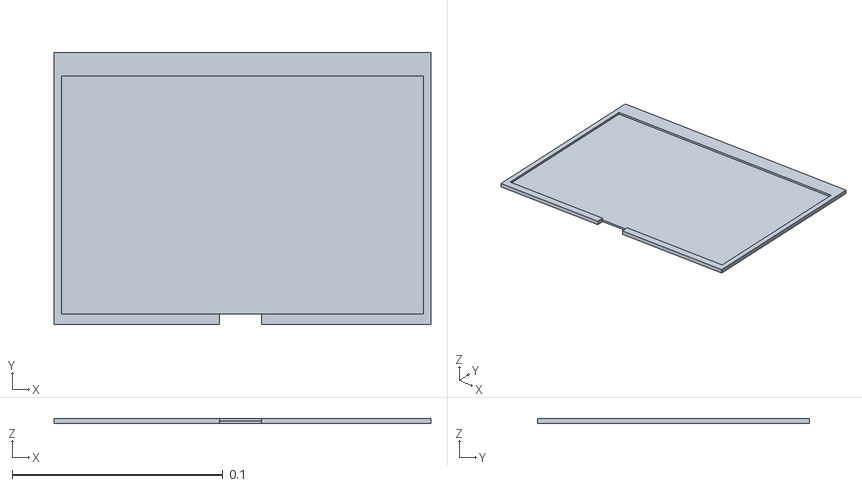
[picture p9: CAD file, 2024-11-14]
docs/3d_model/42_Smart_Sign_display_half.stl
0.179 x 0.129 x 0.0025

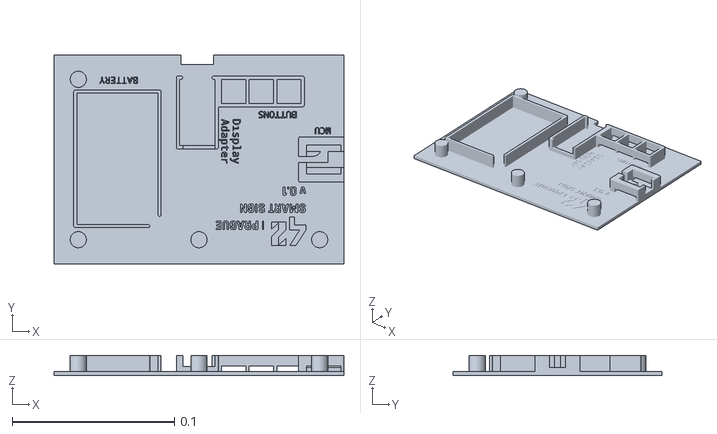
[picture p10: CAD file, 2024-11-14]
docs/3d_model/42_Smart_Sign_components_half.stl
0.179 x 0.129 x 0.0125

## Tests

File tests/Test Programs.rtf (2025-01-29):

Test Programs

This folder contains some of the 42 Smart Cluster Sign functionalities
which were extracted from the main project into their own small programs
for the reasons of testing and debugging. The programs may give some
insight on the development process and help with the future debugging.
All the programs are heavily commented and have notes on some
tests and debugging processes.

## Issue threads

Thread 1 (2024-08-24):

[ISSUE] The Sign may report incorrect Exams status in Telegram chat

RomanAlexandroff, 2024-08-24:
When prompted with the "/status" command in the Telegram chat, the Sign answers with some information about its work including information about exams. If the Sign is prompted before the first wake-up of the day (currently, it is set to 6 AM) or after the last wake-up of the prior day (currently, it is 9 PM), the device always replies with "no exams today" even if there is an exam.

This happens due to the location of the ft_telegram_check() function, which is responsible for answering in the Telegram chat, in the program. This function is located before the function which checks the exams on the 42 Intra server. In short, the Sign outputs information before checking it.

The issue does not occur if the Sign gets prompted after the first wake-up of the day. The issue cannot be fixed simply by moving the ft_telegram_check() function since the function is also responsible for triggering the OTA functionality. Moving it elsewhere would definitely break the OTA functionality.

Since the "/status" command is not intended for the students, but for the 42 employees, whose working days generally start later than 6 AM, it is highly unlikely that this issue will be encountered by the Sign users. Thus, this issue will not be primarily worked on.

Closed 2024-11-07.

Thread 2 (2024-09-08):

[BUG] Data loss over deep sleep

RomanAlexandroff, 2024-09-08:
Over deep sleep, the device "forgets" the name of the Telegram chat it has been written from. It is strange because the variable containing this data is located in the RTC memory therefore its value should persist over deep sleep. The issue may affect all the RTC-stored variables.

RomanAlexandroff, 2024-11-07:
The bug has been resolved with the latest update. It appears that the cause of the issue was the use of String object variables in RTC memory. Refactoring these RTC memory String variables into C-style string arrays has fixed the problem.

Closed 2024-11-07.

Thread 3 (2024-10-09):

[BUG] Telegram falls-off after full flash erase

RomanAlexandroff, 2024-10-09:
After burning new software with full flash erase the Sign looses its Telegram chat ID and all the Telegram functionality becomes unavailable. It means that the remote Secret token update and all the in-chat notifications are off. Rebooting the device does not help. It is probably connected with this issue: [[BUG] Data loss over deep sleep #2](https://github.com/RomanAlexandroff/42-Prague-Smart-Sign/issues/2#issue-2512462232)

RomanAlexandroff, 2024-11-08:
After testing with software version 4.23, the bug could not be replicated. I am marking this issue as resolved. Please, feel free to reopen it if the bug occurs again.

Closed 2024-11-08.

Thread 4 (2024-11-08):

[BUG] Serial port drops off

RomanAlexandroff, 2024-11-08:
The Serial port behaves strangely at the start of the program execution. Immediately after booting up, a few lines of output from the device appear in the Serial monitor, followed by a pause of about 1 second with no new messages. After this pause, the device resumes sending messages as intended. However, I have to restart the Serial monitor to see them. I'm not sure if the device is restarting the Serial port or rebooting completely during that 1-second pause. This bug has no affect on the user experience, but makes debugging slightly more complicated than it has to be.

RomanAlexandroff, 2024-11-09:
The behaviour of the Serial port was caused by the initialisation of the display SPI port. Now that the SPI port initialises first, it no longer interrupts the Serial port.

Closed 2024-11-09.

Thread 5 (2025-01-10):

[BUG] Exam information note fails to display the time

RomanAlexandroff, 2025-01-10:
SW version 4.29. The Sign stopped displaying the exam time in the exam notification notes. The first photo shows the way it used to work and the second photo shows the current state. My assumption is that the watchdog disrupts the execution of the function responsible for drawing the exam time. Unfortunately, as of now, I cannot check it.

{CORRECT OPERATION}
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

{CURRENT BEHAVIOUR}
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

RomanAlexandroff, 2025-01-16:
The issue has been fixed in the SW version 4.32. by increasing the time delay between drawing the text and drawing the exact time from 500 milliseconds all the way to 6000 milliseconds.

Presumably, the issue was caused by introducing a watchdog to the program in the first place. Since the drawing process takes a very long time, the watchdog has to be turned off before the drawing process starts and turned on again after the drawing process is finished. Since drawing the text and drawing the exact time are two separate drawing processes, the watchdog turns on and off again in a very short sequence between them. I assume that the extra time is needed for the underlaying firmware to process the watchdog switching. This solution is sub-optimal and will require further examination.

Closed 2025-01-16.

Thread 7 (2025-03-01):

[BUG] Visual artifacts instead of OTA Update message

RomanAlexandroff, 2025-03-01:
When the Sign attempts to display the service message regarding the Over The Air (OTA) update port being active, it fails to present the message correctly. Instead of the intended notification, the Sign shows visual artifacts that disrupt the user experience.

**Steps to reproduce:**

1. Trigger the OTA update port to open - by pressing the OTA button on the device OR by sending the OTA command in the Telegram chat and waking the Sign up.
2. Observe the display.

**Expected Behaviour:**

- The Sign shall display the cluster number and clearly show a message indicating that the OTA update port is active next to the number.
- After the OTA update port is closed, the Sign shall replace the OTA update port message with the normal state pictograms or another appropriate note.

**Actual Behaviour:**

- The Sign updates a very small part of the display.
- Visual artifacts appear instead of the proper service message.
- After the OTA update port is closed, only the small part of the display refreshes leaving wide red stripe across the screen.

_the behaviour while the OTA port is active_

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

RomanAlexandroff, 2025-03-02:
Solved.
- The text window was very small that is why the display was updating only that small rectangle. That was also the reason why we can see only a fragment of a letter "E" from the word "UPDATE".
- The text window coordinates were also off, that is why the rectangle was in the middle of the display.
- The display did not return to its normal state when the OTA update port was closed because the display did not have enough time to process the second refresh, so it skipped it. Implementing a delay fixed this issue.

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

Closed 2025-03-02.

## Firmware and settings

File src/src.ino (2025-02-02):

/* ************************************************************************** */
/*                                                                            */
/*   42 Smart Cluster Sign                                :::      ::::::::   */
/*   src.ino                                            :+:      :+:    :+:   */
/*                                                    +:+ +:+         +:+     */
/*   By: raleksan <r.aleksandroff@gmail.com>        +#+  +:+       +#+        */
/*                                                +#+#+#+#+#+   +#+           */
/*   Created: 2024/04/09 12:50:00 by raleksan          #+#    #+#             */
/*   Updated: 2024/11/27 13:20:00 by raleksan         ###   ########.fr       */
/*                                                                            */
/* ************************************************************************** */

#include "42-Smart-Cluster-Sign.h"

void  setup(void)
{
    ft_watchdog_init();
    ft_display_init();
    #ifdef DEBUG
        ft_serial_init();
    #endif
    ft_spiffs_init();
    ft_buttons_init();
    ft_battery_init();
    ft_power_down_recovery();
    ft_battery_check();
    ft_telegram_check();
    ft_ota_init();
}

void  loop(void)
{
    ft_ota_waiting_loop();
    ft_pathfinder();
}

static void  ft_pathfinder(void)
{
    unsigned int  sleep_length;

    ft_watchdog_reset();
    if (rtc_g.exam_status)
        ft_exam_mode();
    if (!rtc_g.exam_status)                         // do not change
        ft_cluster_number_mode(&sleep_length);
    ft_go_to_sleep(sleep_length);
    DEBUG_PRINTF("  ---- This message will never be printed out");
}
 

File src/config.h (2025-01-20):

/* ************************************************************************** */
/*                                                                            */
/*                                                        :::      ::::::::   */
/*   config.h                                           :+:      :+:    :+:   */
/*                                                    +:+ +:+         +:+     */
/*   By: raleksan <r.aleksandroff@gmail.com>        +#+  +:+       +#+        */
/*                                                +#+#+#+#+#+   +#+           */
/*   Created: 2024/12/09 16:20:00 by raleksan          #+#    #+#             */
/*   Updated: 2024/12/18 13:00:00 by raleksan         ###   ########.fr       */
/*                                                                            */
/*                                                                            */
/*   The following values are adjustable for tuning the software behavior.    */
/*   You may also find some configurations in credentials.h                   */
/*                                                                            */
/* ************************************************************************** */

#ifndef CONFIG_H
# define CONFIG_H

# define SOFTWARE_VERSION       4.32
# define DEVICE_NAME            "42 Prague Smart Sign"

# define DEBUG                                               // comment out this line to turn off Serial output
# ifdef DEBUG
    #define DEBUG_PRINTF(...)   Serial.printf(__VA_ARGS__)
    #define WD_RESET_INFO       true
# else
    #define DEBUG_PRINTF(...)
    #define WD_RESET_INFO       false
# endif

//# define EXAM_SIMULATION                                   // uncomment to simulate an exam today starting at the stated time

# pragma GCC optimize           ("O3")                       // optimize for faster program performance
# define BAUD_RATE              115200                       // speed of the Serial communication
# define WAKE_UP_HOURS          6, 9, 12, 15, 18, 21         // e.g. 15 means 15:00
# define RETRIES_LIMIT          3                            // for getting time and exam info
# define TIME_ZONE              1                            // campus time zone according to the GMT standart

/* Time limits */
# define CONNECT_TIMEOUT_S      5                            // wi-fi
# define DEBOUNCE_DELAY_MS      1000ul                       // buttons
# define WD_TIMEOUT_MS          8000                         // watchdog
# define OTA_WAIT_LIMIT_S       600                          // 10 minutes
# define SERVER_WAIT_MS         1000                         // Intra
# define SUBS_CHECK_LIMIT_MS    3900000ul                    // 1 hour 5 minutes
# define DEAD_BATTERY_SLEEP_MS  86400000ull                  // 24 hours

/* Battery config */
# define BATTERY_CRITICAL       400
# define BATTERY_GOOD           800
# define BATTERY_SAMPLES_LIMIT  5

#endif
 

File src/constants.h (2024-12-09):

/* ************************************************************************** */
/*                                                                            */
/*                                                        :::      ::::::::   */
/*   constants.h                                        :+:      :+:    :+:   */
/*                                                    +:+ +:+         +:+     */
/*   By: raleksan <r.aleksandroff@gmail.com>        +#+  +:+       +#+        */
/*                                                +#+#+#+#+#+   +#+           */
/*   Created: 2024/04/09 13:00:00 by raleksan          #+#    #+#             */
/*   Updated: 2024/12/09 16:30:00 by raleksan         ###   ########.fr       */
/*                                                                            */
/*                                                                            */
/*   The following constants are not expected to be changed at any point.     */
/*                                                                            */
/* ************************************************************************** */

#ifndef CONSTANTS_H
# define CONSTANTS_H

/* General constants */
# define WD_NUMBER_OF_CORES      1                            // watchdog
# define REBOOT                  1000
# define mS_TO_uS_FACTOR         1000ull                      // milliseconds to microseconds
# define mS_TO_S_FACTOR          1000ul                       // milliseconds to seconds
# define MINUTE_MS               60000
# define HOUR_MS                 3600000
# define MONTHS_DAYS             31, 28, 31, 30, 31, 30, 31, 31, 30, 31, 30, 31
# define YEAR_DAYS               365
# define NOT_FOUND               -1
# define FAILED_TO_COUNT         -128
# define MIN_SLEEP_LIMIT_MS      100ull                       // deep sleep, 0.1 seconds
# define MAX_SLEEP_LIMIT_MS      172800000ull                 // deep sleep, 48 hours

/* Buttons */
# define DIAGNOSTICS_BUTTON      D0
# define OTA_BUTTON              D1
# define WARNING_BUTTON          D2
# define GPIO_MASK               (1ULL << DIAGNOSTICS_BUTTON) | (1ULL << OTA_BUTTON) | (1ULL << WARNING_BUTTON)

/* Display SPI port */
# define BUSY_PIN                D4
# define RST_PIN                 D5
# define DC_PIN                  D6
# define SPI_SS_PIN              D7
# define SPI_SCK_PIN             D8
# define SPI_MISO_PIN            -1
# define SPI_MOSI_PIN            D10

/* Display driver */
# define GxEPD2_DISPLAY_CLASS    GxEPD2_3C
# define GxEPD2_DRIVER_CLASS     GxEPD2_750c_Z08
# define GxEPD2_3C_IS_GxEPD2_3C  true
# define IS_GxEPD2_3C(x)         IS_GxEPD(GxEPD2_3C_IS_, x)
# define MAX_DISPLAY_BUFFER_SIZE 96124ul
# define MAX_HEIGHT(EPD)         (EPD::HEIGHT <= (MAX_DISPLAY_BUFFER_SIZE / 2) / (EPD::WIDTH / 8) ? EPD::HEIGHT : (MAX_DISPLAY_BUFFER_SIZE / 2) / (EPD::WIDTH / 8))

/* Images constants */
typedef enum {
    CLUSTER = 1000,
    DEFAULT_IMG,
    INTRA_ERROR,
    SECRET_EXPIRED,
    EXAM_DAY,
    LOW_BATTERY,
    DEAD_BATTERY,
    OTA_WAITING,
    OTA_SUCCESS,
    OTA_FAIL,
    OTA_CANCELED,
    TELEGRAM_ERROR,
    TELEGRAM_STATUS
} IMAGE_t;

/* Errors constants */
typedef enum {
    UNKNOWN = 2000,
    TIME_OK,
    TIME_NO_WIFI,
    TIME_NO_SERVER,
    TIME_NO_DST,
    INTRA_OK,
    INTRA_NO_SERVER,
    INTRA_NO_TOKEN,
    INTRA_NO_INFO,
    FS_OK,
    FS_INIT_FAIL,
    FS_OPEN_FAIL,
    FS_EMPTY_FILE,
    FS_ENTRY_ERROR,
    FS_VALID_SECRET,
    FS_INVALID_SECRET,
    FS_NOT_A_SECRET
} ERROR_t;

#endif
 

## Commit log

2024-03-01 fix names of global RTC variables
    [battery_management.cpp, buttons_handling.cpp, other.cpp]
2024-03-02 implement warning sign button status
2024-03-06 implement measurements correctness detection
    [battery_management.cpp]
2024-03-12 calibrate settings for display to use less RAM
2024-03-12 add Intra error and low battery handling
2024-03-13 fix bug when battery max value could be recorded as a min value as well
    [battery_management.cpp]
2024-03-13 fix the program getting stuck
    [42-Prague-Smart-Sign.ino]
2024-03-13 fix the Wi-Fi connection getting stuckw
    [other.cpp]
2024-03-15 fix minor compilation error
    [display_handling.cpp]
2024-04-09 add multiplatform support, add Secret expiration tracking, add Secret quick update via Telegram, replace EEPROM with LittleFS, add Secret recovery after power loss, add exeptions and errors handling
    [42-Prague-Smart-Sign.ino, battery_management.cpp, buttons_handling.cpp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]
2024-04-09 add multiplatform support, add Secret expiration tracking, add Secret quick update via Telegram, replace EEPROM with LittleFS, add Secret recovery after power loss, add exceptions and errors handling
    [42-Prague-Smart-Sign.ino, battery_management.cpp, buttons_handling.cpp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]
2024-04-11 board definition correction
2024-04-12 fix bug when exam state can exit into sleep instead of the cluster number mode
    [42-Prague-Smart-Sign.ino]
2024-04-13 fix compilation bug caused by multiple display and SPI pins definitions
    [constants.h]
2024-05-13 refactored battery status tracking
2024-05-16 remove global battery variable and struct
2024-05-16 implement buttons
2024-06-05 fully refactored OTA, add buttons wake up from deep sleep
2024-07-20 implement protection to prevent infinite sleep
    [other.cpp]
2024-08-13 fix SSL connection buffer overflow
    [constants.h]
2024-08-18 fix wake-up time calculation
    [other.cpp]
2024-08-20 fix being unable to wake up when exam detected less than 1 hour before the exam
    [constants.h, other.cpp]
2024-08-23 add graphical materials folder
2024-08-23 add device photos
2024-08-31 add new constants for battery management
2024-09-11 fix faulty implementation of reading a file
    [constants.h]
2024-10-22 introduce ERROR enum and Telegram notifications for Intra errors
    [constants.h, display_handling.cpp]
2024-10-22 introduce ERROR enum and Telegram notifications for Get Time errors
    [constants.h]
2024-11-02 refactor switch statement for readability
2024-11-07 solve RTC memory issue: refactor rtc_g.Secret and rtc_g.chat_id from String into char* type
    [battery_management.cpp, constants.h]
2024-11-07 solve RTC memory issue: refactor rtc_g.from_name from String into char* type
    [constants.h]
2024-11-08 comment-out unused functionality for buttons
2024-11-08 add AP MAC address to the device status Telegram message
2024-11-09 fix errasing of Low Battery warning and add debug messages
    [display_handling.cpp]
2024-11-09 fix Serial port failing at the start
    [42-Prague-Smart-Sign.ino]
2024-11-12 make button functionality operational
2024-11-14 add button connection schematics
2024-11-14 add project documents and external tools
    [42_Smart_Sign_components_half.stl, 42_Smart_Sign_display_half.stl, Bill_of_Materials.xlsx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]
2024-11-28 add device name for OTA port
2024-11-29 fix calculation of the Secret token expiration
    [constants.h, other.cpp]
2024-12-08 update to esp32 board v. 3.0.7: watchdog timer
2024-12-08 update to esp32 board v. 3.0.7: ADC config
2024-12-08 update to esp32 board v. 3.0.7: the DEBUG macro update
2025-01-11 fix bug of not receiving server replies
    [config.h]
2025-01-15 fix exam time not displaying in the exam warning note
    [display_handling.cpp]
2025-01-26 Update Jenkinsfile to use local arduino-cli binary
2025-01-30 update Jenkinsfile to print environment variables and verify paths
2025-02-01 remove Run Tests stage and SERIAL_PORT variable, update Jenkinsfile to upload binary to Updates server
2025-02-02 project renaming
    [Bill_of_Materials.xlsx]
